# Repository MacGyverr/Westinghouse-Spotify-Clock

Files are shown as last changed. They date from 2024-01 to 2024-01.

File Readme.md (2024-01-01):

# Westinghouse H816L5 Clock Spotify Conversion
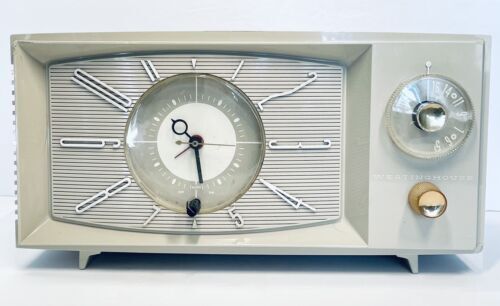
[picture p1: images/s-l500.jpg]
Westinghouse H816L5 Clock

## Overview
I replicated a Westinghouse H816L5 clock in TinkerCAD to design parts for mounting a Raspberry Pi and a modern clock, transforming it into a Spotify speaker.

- TinkerCAD Model: [Westinghouse H816L5 Clock Conversion - WIP](https://www.tinkercad.com/things/fx6p13KGLE0-westinghouse-h816l5-clock-conversion-wip)
  
The project involved some modifications to the original structure, including grinding down the internal lip. It uses Raspotify and Spotipy, controlled by a Python script. It features three rotary encoders for track control, power/play/pause/volume, and playlist navigation.

## Hardware Requirements
- [Raspberry Pi 4](https://www.amazon.com/gp/product/B07TD43PDZ)
- MIC ULTRA+ (as an amplifier) [Link](https://raspiaudio.com/produit/ultra)
- 3 [Rotary Encoders](https://www.amazon.com/gp/product/B07T3672VK)
- [3 WS2812B LEDs](https://www.amazon.com/gp/product/B01CDTEG1O/)
- Rotary Encoder #1 to GPIO pins 16, 12, 26 (Clock, Data, Button)
- Rotary Encoder #2 to GPIO pins 5, 6, 13 (Clock, Data, Button)
- Rotary Encoder #3 to GPIO pins 22, 27, 17 (Clock, Data, Button)
- [Radio Setting Clock](https://www.amazon.com/gp/product/B08CV4481V/)
- New [4" Shielded Speaker](https://www.amazon.com/gp/product/B0002ZPSPA)
- WS2812B to GPIO pin 10 (Data for LEDs)

## Software
- [Raspberry Pi OS](https://www.raspberrypi.com/software/operating-systems/)
- [Raspotify](https://dtcooper.github.io/raspotify/)
- [Spotipy](https://spotipy.readthedocs.io/)
- [Spotify API](https://developer.spotify.com/dashboard)

## Installation and Setup
1. **Prepare the Raspberry Pi:**
    ```bash
    sudo apt-get -y update
    sudo apt-get -y upgrade
    sudo apt-get -y install git pip espeak
    ```

2. **Configure Rotary Encoders in `config.txt`:**
    ```bash
    sudo nano /boot/config.txt
    # Add the following lines
    dtoverlay=rotary-encoder,pin_a=16,pin_b=12,relative_axis=1
    dtoverlay=gpio-key,gpio=26,keycode=30,label="A"
    dtoverlay=rotary-encoder,pin_a=5,pin_b=6,relative_axis=1
    dtoverlay=gpio-key,gpio=13,keycode=48,label="B"
    dtoverlay=rotary-encoder,pin_a=22,pin_b=27,relative_axis=1
    dtoverlay=gpio-key,gpio=17,keycode=46,label="C"
    ```
    After editing, reboot and test with `evtest`.

3. [**Install Audio Hat Drivers for MIC ULTRA+:**](https://forum.raspiaudio.com/t/ultra-installation-guide/21)
    ```bash
    git clone https://github.com/RASPIAUDIO/ultra2
    cd ultra2
    sudo ./install.sh
    sudo reboot
    ```

4. **Install and Configure Raspotify:**
    - Follow the guide at [Raspotify](https://dtcooper.github.io/raspotify/)
    - Edit `/etc/raspotify/conf` as per the provided `conf` file.
    - Restart the service and set volumes using `alsamixer`.

5. **Install Spotipy and Additional Packages:**
    ```bash
    sudo pip install spotipy
    sudo pip install adafruit-circuitpython-neopixel
    sudo pip3 install pyttsx3
    ```

6. **Setup Python Script for Control:**
    ```bash
    mkdir westinghouse
    cd westinghouse/
    nano monitor_input.py
    # Paste in the contents of the "monitor_input.py" file
    chmod +x monitor_input.py
    ```

7. [**Configure Spotify API Credentials:**](https://stackoverflow.com/questions/33444733/setting-spotify-credentials-using-spotipy)
    ```bash
    export SPOTIPY_CLIENT_ID='xxxxxxxxxxxxxxxxxxxxxxxx'
    export SPOTIPY_CLIENT_SECRET='xxxxxxxxxxxxxxxxxxxx'
    export SPOTIPY_REDIRECT_URI='http://localhost:8080/callback'
    ```

8. **Setup Python Script as a Service:**
    ```bash
    sudo nano /etc/systemd/system/monitor_input.py.service
    # Paste in the contents of the "monitor_input.py.service" file
    sudo systemctl enable monitor_input.py
    sudo systemctl daemon-reload
    sudo systemctl start monitor_input.py
    systemctl | grep running
    ```

9. **Automatic Reboot Setup:**
    ```bash
    sudo crontab -e
    # Add this line for nightly reboot
    0 2 * * * /sbin/shutdown -r now
    ```

## Additional Notes
- Wiring diagram will be added soon.
- TinkerCAD files allow for printing the complete clock and even creating molds for a new lens. (untested)
- The system is set to read only "Overlay" mode and reboots nightly for stability.

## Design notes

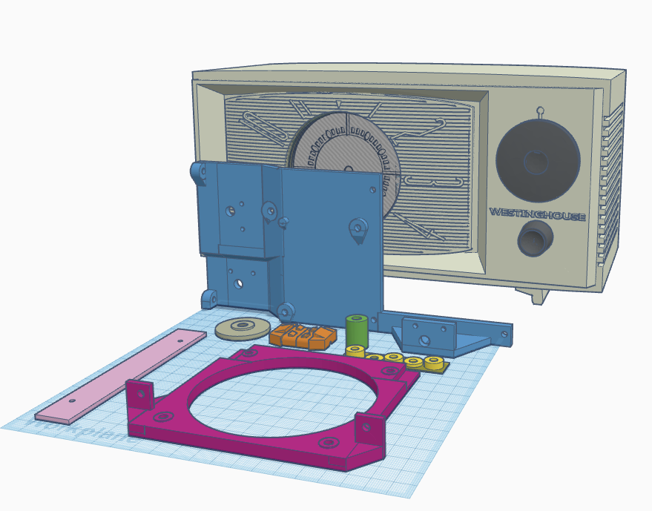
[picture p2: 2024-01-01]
images/design.PNG

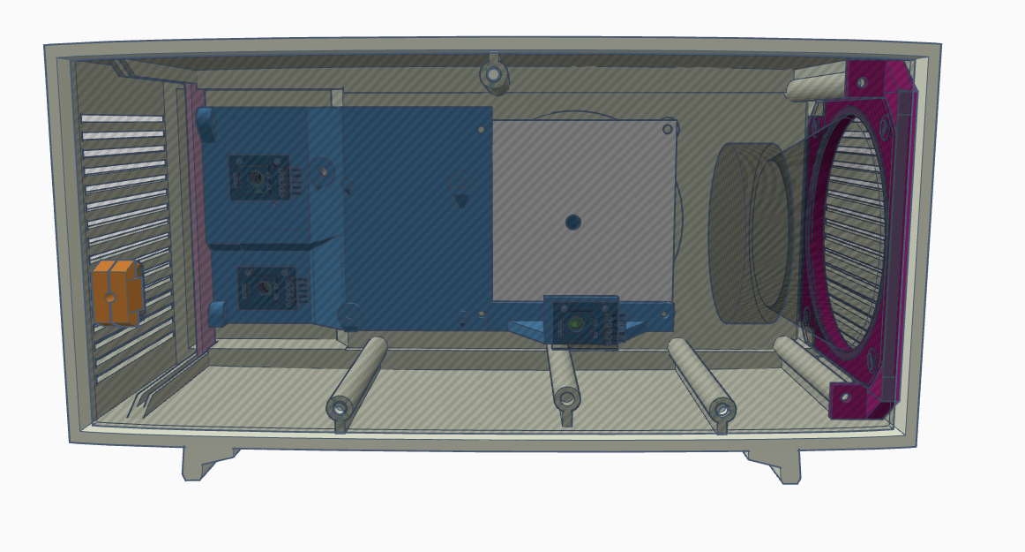
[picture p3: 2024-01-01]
images/design3.PNG

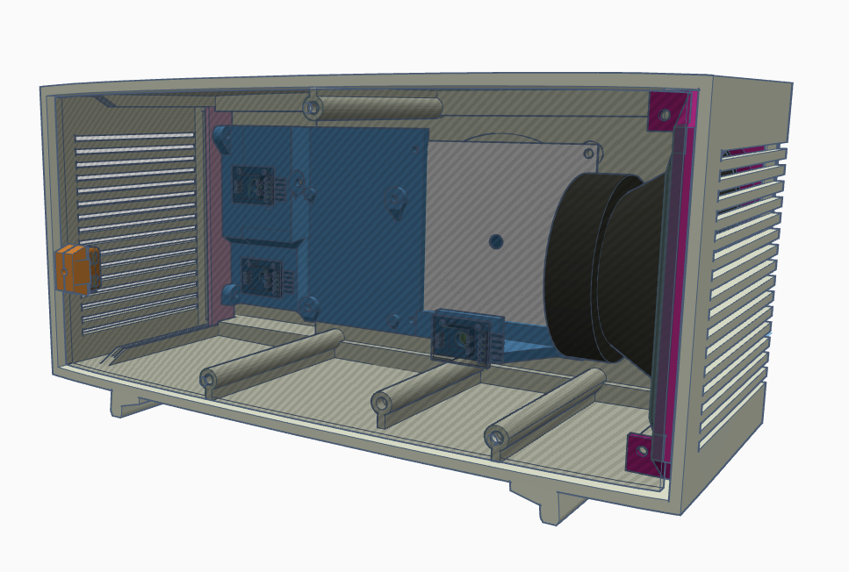
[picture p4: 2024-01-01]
images/design4.PNG

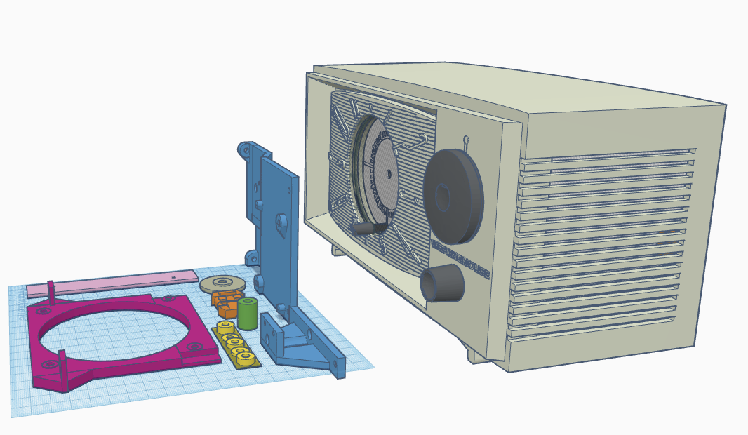
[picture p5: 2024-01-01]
images/design2.PNG

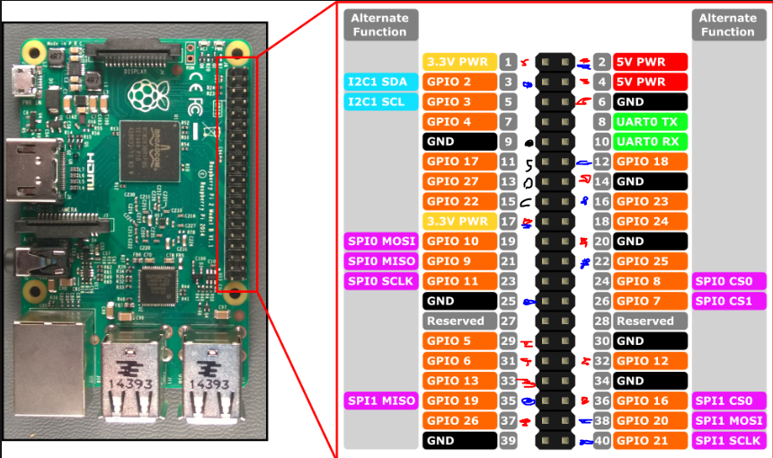
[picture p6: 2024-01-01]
images/wiremap-wip.PNG

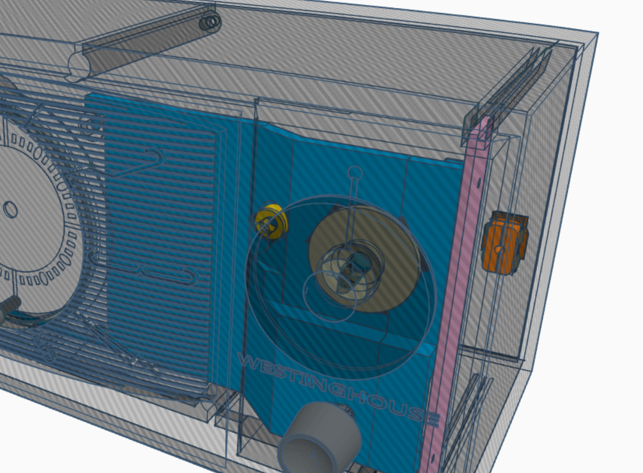
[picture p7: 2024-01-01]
images/diffusor.PNG

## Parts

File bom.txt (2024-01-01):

https://www.amazon.com/gp/product/B08CV4481V/
https://www.amazon.com/gp/product/B07T3672VK
https://www.amazon.com/gp/product/B09CYZNRWP
https://www.amazon.com/gp/product/B0002ZPSPA
https://www.amazon.com/gp/product/B07TD43PDZ
https://www.amazon.com/gp/product/B08HVQQSWP
https://www.amazon.com/uxcell-Knurled-Insert-Female-Embedding/dp/B09MCWTBCC/

https://www.ebay.com/sch/i.html?_nkw=Westinghouse+H816L5+Clock

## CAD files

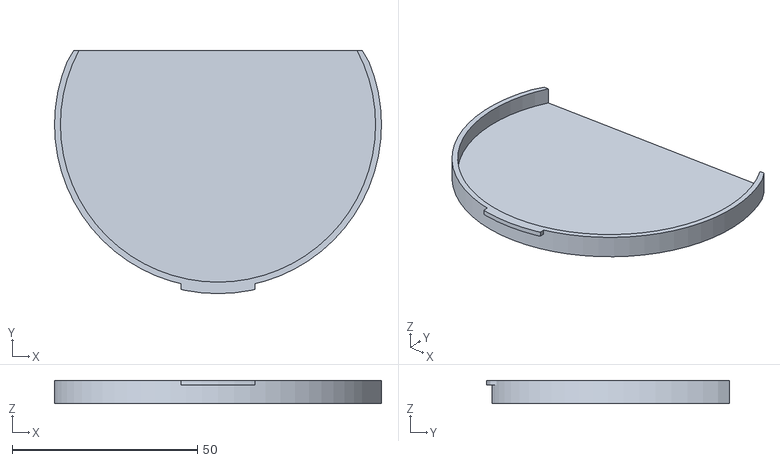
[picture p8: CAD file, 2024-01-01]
STLs/replacement-clock-face.stl
88.2 x 65.6 x 6.25

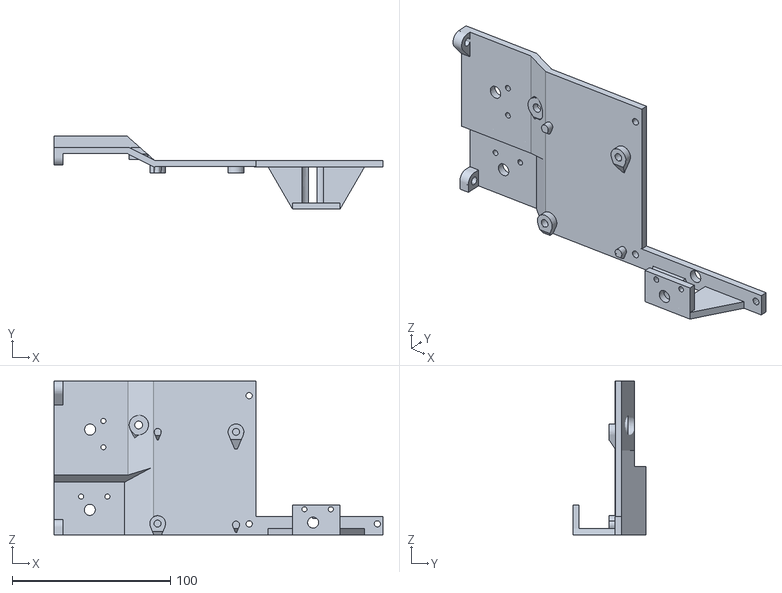
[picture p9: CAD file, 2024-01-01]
STLs/mounting-plate.stl
208.0 x 46.3 x 97.3

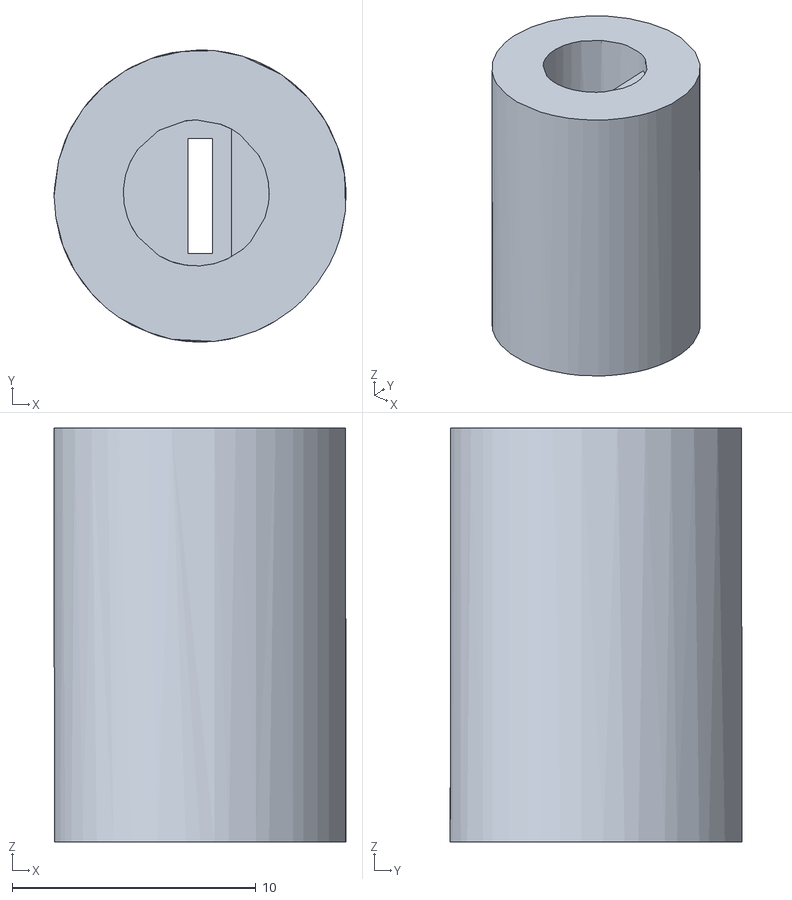
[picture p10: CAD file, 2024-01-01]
STLs/playlist-extension-rod.stl
12.0 x 12.0 x 17.0

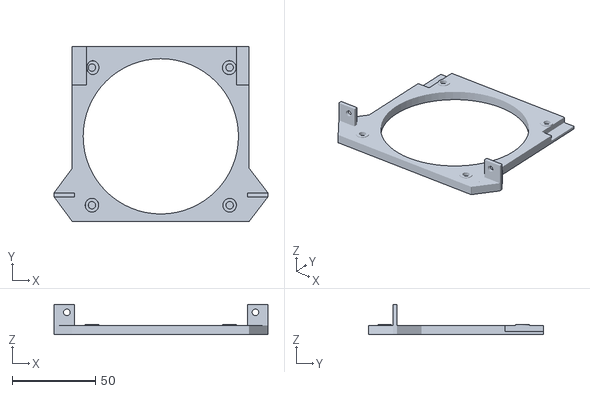
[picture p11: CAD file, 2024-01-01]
STLs/speaker-adapter.stl
128.5 x 105.1 x 18.2

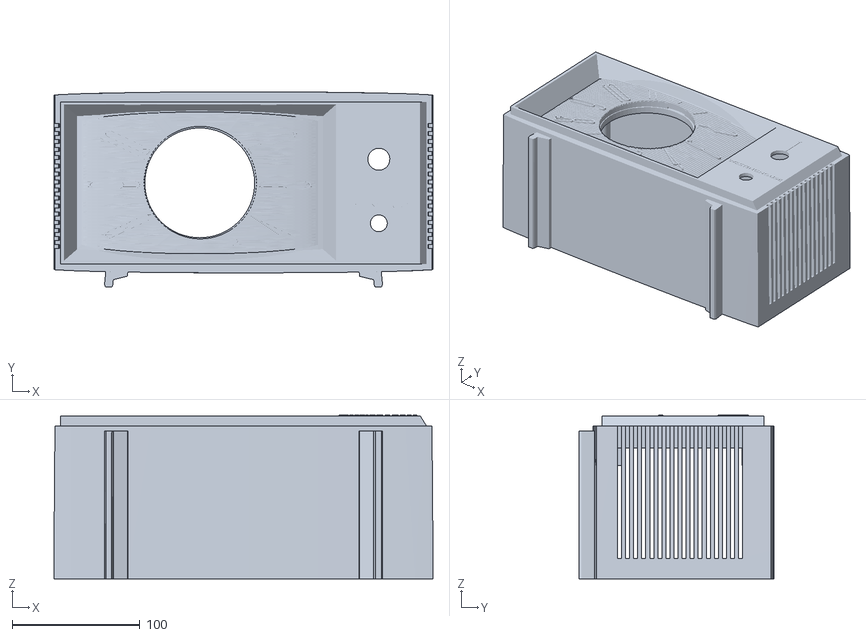
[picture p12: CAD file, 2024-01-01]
STLs/replacement-Westinghouse H816L5.stl
297.0 x 153.1 x 128.2

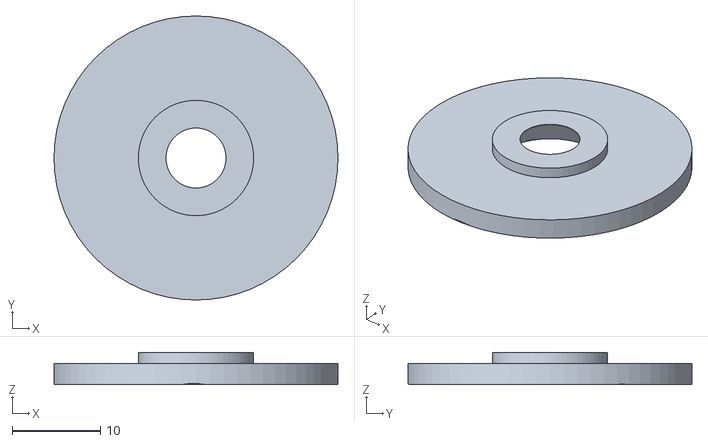
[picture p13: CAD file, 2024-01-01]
STLs/diffusor.stl
32.2 x 32.2 x 3.65

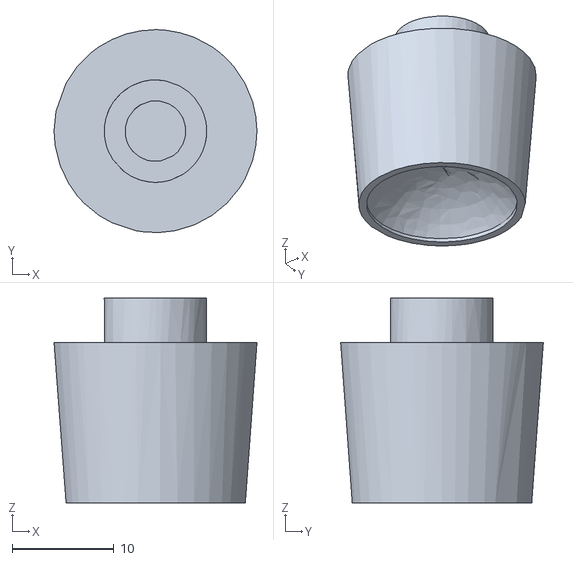
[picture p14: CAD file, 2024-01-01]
STLs/replacement-volume-knob.stl
20.0 x 20.0 x 20.2

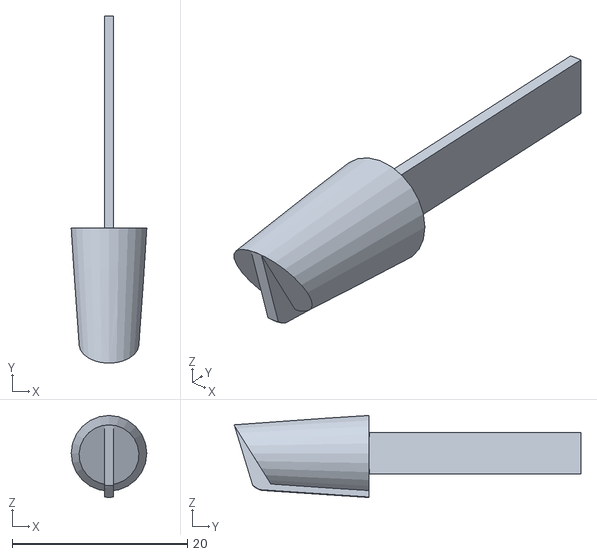
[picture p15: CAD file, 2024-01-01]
STLs/replacement-preset-knob.stl
8.64 x 39.6 x 9.38

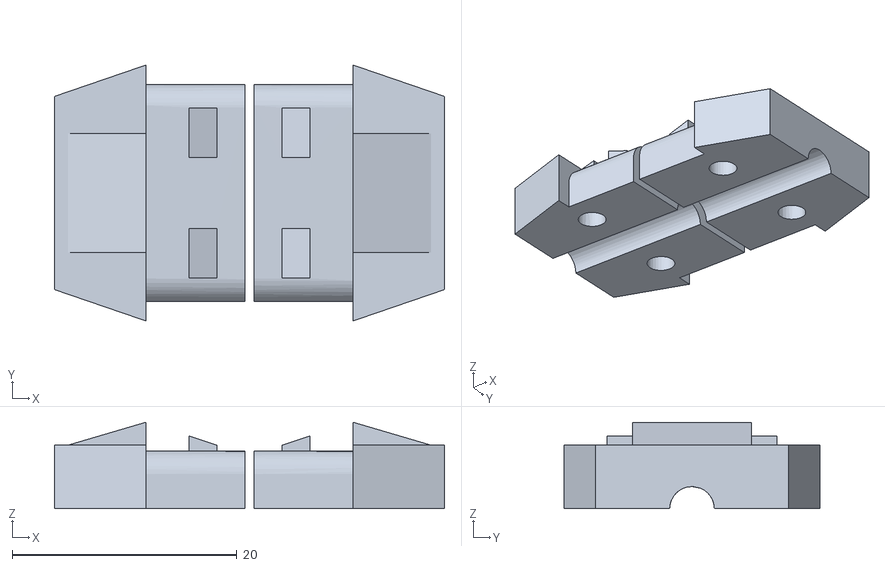
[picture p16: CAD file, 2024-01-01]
STLs/cord-plug.stl
34.7 x 22.8 x 7.70

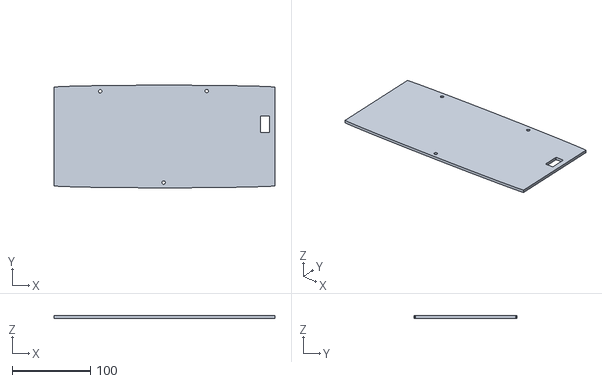
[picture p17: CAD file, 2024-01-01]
STLs/replacement-back.stl
282.0 x 131.0 x 3.50

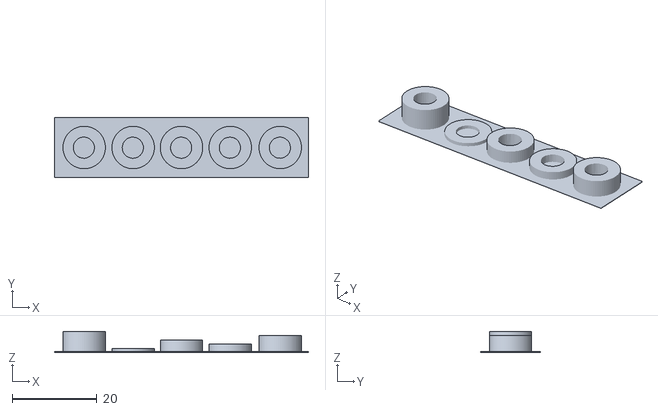
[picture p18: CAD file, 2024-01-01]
STLs/spacer-multiple.stl
59.8 x 14.1 x 5.00

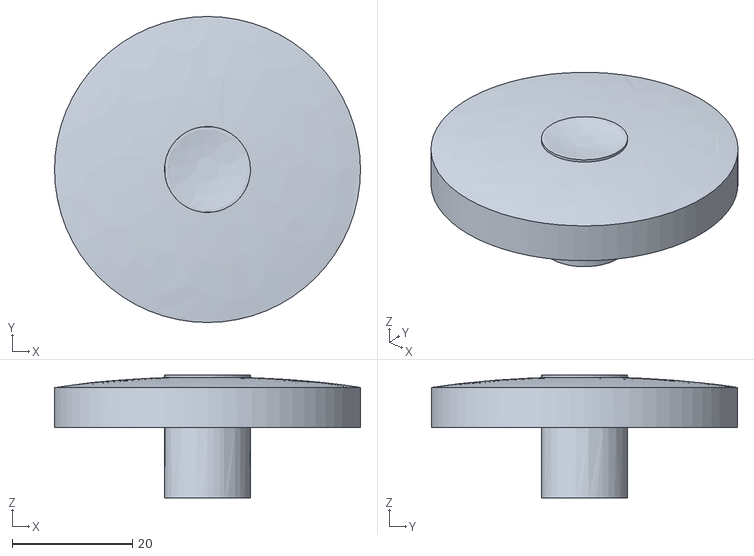
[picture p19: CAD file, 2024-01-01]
STLs/replacement-selection-knob.stl
50.9 x 50.9 x 20.4

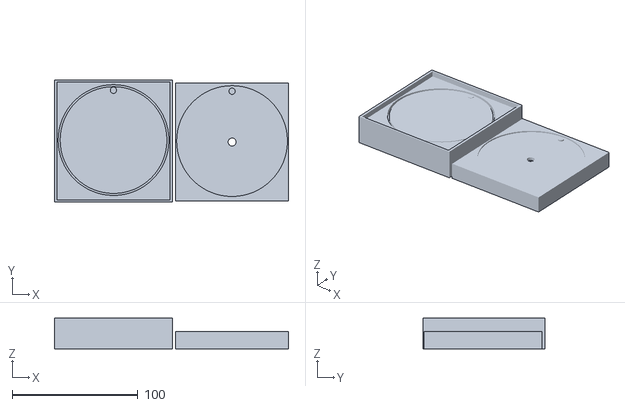
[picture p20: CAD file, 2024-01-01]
STLs/replacement-clock-face-mould.stl
186.3 x 97.0 x 24.6

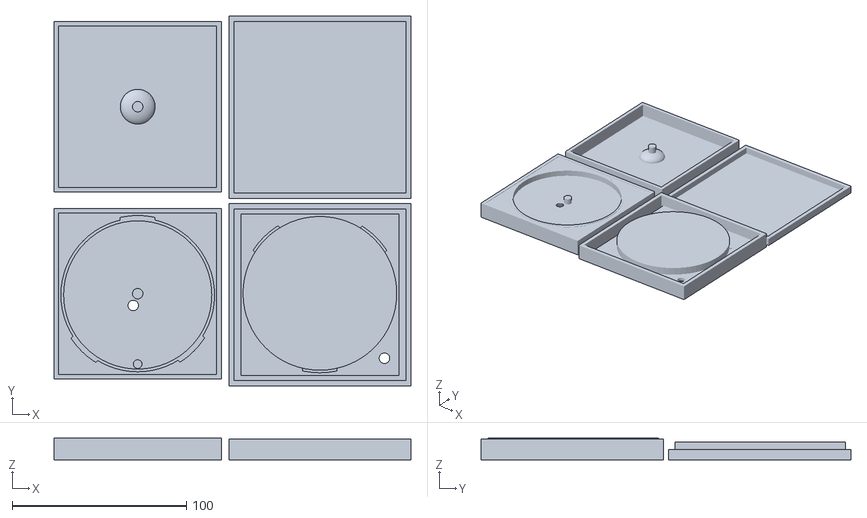
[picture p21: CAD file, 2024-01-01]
STLs/replacement-clock-face-mould-mould.stl
204.9 x 212.2 x 12.6

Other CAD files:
STLs/replacement-face.stl
STLs/mounting-plate-support.stl

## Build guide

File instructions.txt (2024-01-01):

Westinghouse H816L5 Clock Conversion-WIP

I use a MIC ULTRA+ as an amplifier, if you don't skip that part.
It runs Raspotify and Spotipy and an awful python program I wrote to control Spotipy. 
It has 3 rotary encoders, 1 for track next/prev/shuffle, 1 for power/play/pause/vol, and 1 for playlist prev/next.

You will need to follow the online guides for how to register your system to make API calls from Spotify.
You will populate various config files with the keys and userIDs you get from Spotify.

I'm in the process of trying to re-create instructions for someone to make one themselves.
It has issues, I throttle the API calls to Spotify (so it doesn't crash) and this makes it have a "1 command a second" interface, this is fine for the track and playlist knobs but makes turning the volume up or down a pain. This can be adjusted or tuned in if you know python.

Here is the WIP of the process, it is not complete, some may be unneed, some may have changed since I built it. It is what I remember and should at least help you find the info for each support program.

I will update this as I can, but you should use the specific online links for the various support programs.

#Install the packages
sudo apt-get -y update
sudo apt-get -y upgrade
sudo apt-get -y install git
sudo apt-get -y install pip
sudo apt-get -y install espeak

#I add the rotary encoders as dtoverlay devices in config.txt so that they are stable and work correctly in python.
sudo nano /boot/config.txt
dtoverlay=rotary-encoder,pin_a=16,pin_b=12,relative_axis=1
dtoverlay=gpio-key,gpio=26,keycode=30,label="A"

dtoverlay=rotary-encoder,pin_a=5,pin_b=6,relative_axis=1
dtoverlay=gpio-key,gpio=13,keycode=48,label="B"

dtoverlay=rotary-encoder,pin_a=22,pin_b=27,relative_axis=1
dtoverlay=gpio-key,gpio=17,keycode=46,label="C"

sudo reboot
evtest

#Get the audio hat drivers for the MIC ULTRA+ https://raspiaudio.com/produit/ultra
git clone https://github.com/RASPIAUDIO/ultra2
cd ultra2
sudo ./install.sh
sudo reboot

#Install Raspotify (use their guide at) https://dtcooper.github.io/raspotify/
sudo apt-get -y install curl && curl -sL https://dtcooper.github.io/raspotify/install.sh | sh
sudo nano /etc/raspotify/conf
#make the changes used in the included "conf" file

sudo systemctl restart raspotify

aplay -l
aplay -Dhw:2 --dump-hw-params /usr/share/sounds/alsa/Front_Right.wav

# I use a audio hat, if you don't or use a different one then either skip this or use your own.
sudo nano /etc/asound.conf
#make the changes used in the included "asound.conf" file
speaker-test -c2 -l1

#set the volumes
alsamixer

# I use Spotipy to control the stream from the 3 rotary encoders
sudo pip install spotipy

# I use ws2812 LEDs on a diffusor to light up the track/shuffle knob from behind
sudo pip install adafruit-circuitpython-neopixel

# I use espeak and pyttsx3 to speak the commands and playlist names
sudo pip3 install pyttsx3

#Here is the horrible python program I wrote to control the stream with the knobs.
mkdir westinghouse
cd westinghouse/
nano monitor_input.py
#make the changes used in the included "monitor_input.py" file
chmod +x monitor_input.py

#I feel like I needed to do this at some point to make Spotify work, maybe not, I'll update as needed.
export SPOTIPY_CLIENT_ID='xxxxxxxxxxxxxxxxxxxxxxxx'
export SPOTIPY_CLIENT_SECRET='xxxxxxxxxxxxxxxxxxxx'
export SPOTIPY_REDIRECT_URI='http://localhost:8080/callback'

#I do this to make the python control script start at startup and run as a service
sudo nano /etc/systemd/system/monitor_input.py.service
#make the changes used in the included "monitor_input.py.service" file

sudo systemctl enable monitor_input.py
sudo systemctl daemon-reload
sudo systemctl start monitor_input.py
sudo systemctl status monitor_input.py
systemctl | grep running

# I put the whole thing in "Overlay" mode when it's done, and have it reboot every night with this cron job.

sudo crontab -e
#make the following changes to have it reboot nightly (so it appears stable during the day)
0 2 * * * /sbin/shutdown -r now
